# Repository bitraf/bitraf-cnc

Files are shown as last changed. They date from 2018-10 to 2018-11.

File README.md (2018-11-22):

# Bitraf-cnc
CNC-related research and projects at Bitraf

 config/	configuration for our machines

 docs/		documentation

 docs/shopbot	document Shopbot specifics
 
 [Hrbl-shopbot edition a new arduino and GRBL powered controller card for the bitraf shopbot](Hrbl-shield_readme.md)
 
 [Please contribute by discussing the open Issues!](https://github.com/bitraf/bitraf-cnc/issues)

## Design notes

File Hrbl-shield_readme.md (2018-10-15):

# Hrbl - Grbl connection shield for Arduino Nano, Shopbot version

## Status

* Under development, this is a fork of the [Hrbl shield for integrated motors](https://github.com/fellesverkstedet/fabricatable-machines/blob/master/hrbl-shield/README.md) from the [Fabricatable Machines project](https://github.com/fellesverkstedet/fabricatable-machines/wiki)
* To help, go to the [issues](https://github.com/bitraf/bitraf-cnc/issues) and find out what needs to be done or raise new issues

## Features

* A fabricatable replacement controller card for the [Shopbot PRSalpha](http://www.shopbottools.com/mProducts/prSalpha.htm)
* It has a Arduino Nano running [GRBL](https://github.com/gnea/grbl/wiki) which does the motion planning.
* It can be fed with gcode over USB using [Octoprint](https://octoprint.org/download/) or [Universal Gcode sender](https://winder.github.io/ugs_website/)
* Pluggable connections that combine all connections needed per axis in one connector per motor *(Needs work!)*
* Full optoisolation separates the computer-arduino circuit from all signal and power wires.
* Z axis milling bit probe connection with external pull-up
* Spindle on/off and speed control *(Needs work!)*
* External power loss detection, keeps the controller in ABORT mode when there is no power to the motors.
* The 2 sided card can be CNC milled with a Ø0.4 mm milling bit 
* Laser cuttable solder mask and silkscreen

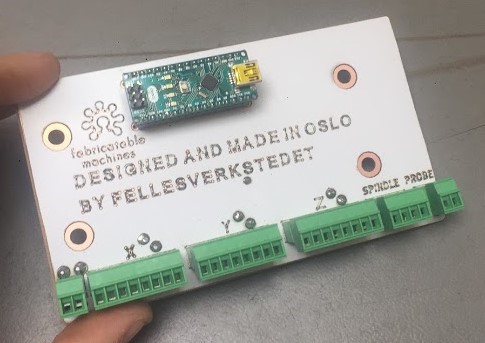
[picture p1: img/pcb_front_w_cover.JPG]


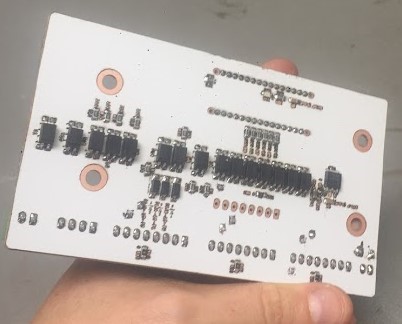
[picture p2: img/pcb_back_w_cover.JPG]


*The HRLB card that was made for [Hedy](https://github.com/fellesverkstedet/fabricatable-machines/blob/master/hedy-pcb-cnc/readme.md#hedy-pcb-mill)*

### Connections

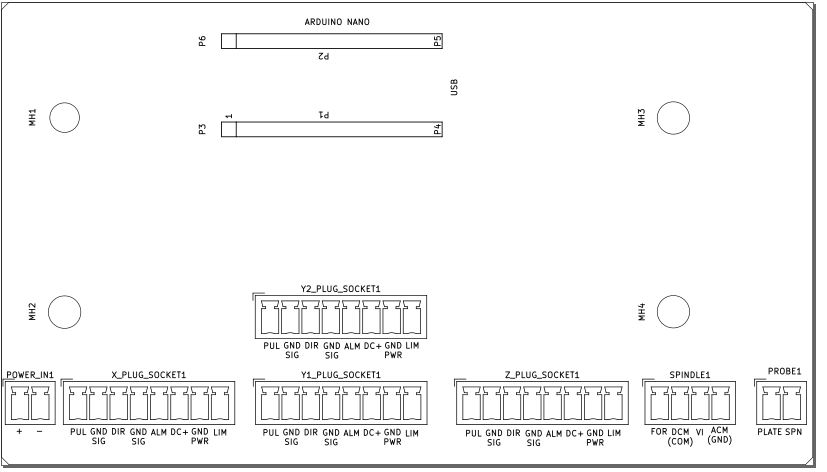
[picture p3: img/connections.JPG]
Connections


[Connections SVG](img/hrbl_shield.svg)

*These need to be reconfigured to match the connections on the shobot*

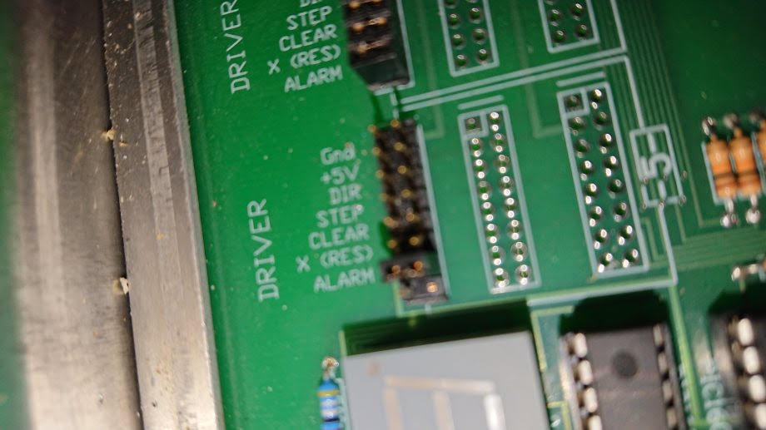
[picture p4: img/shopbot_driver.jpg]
shopbot driver pins


*Shopbot driver pins*

* Question: How does the shopbot controller connect to the limit switches?

## Files

* [All dxf files for milling and laser engraving the foil](Hrbl_for_shopbot/nano-all_DXFs.zip)
* [BOM PDF](Hrbl_for_shopbot/nano_BOM.pdf)
* [BOM ODS format](Hrbl_for_shopbot/nano_BOM.ods)

### Status

HRBL for integrated motor drivers is currently in use in:
* [Hedy v1](https://github.com/fellesverkstedet/fabricatable-machines/blob/master/hedy-pcb-cnc/readme.md) A CNC milling machine made to mill circuit boards like this one.
* [Humphrey v3](https://github.com/fellesverkstedet/fabricatable-machines/blob/master/humphrey-large-format-cnc/humphrey_v3/Readme.md) A large size CNC milling machine built as a kit by Makerspace in Brumundal.

### Firmware for the Arduino NANO

* Download this repo and go into the [Hrbl_for_shopbot/grbl_spindle_enable_no_alarm_on_boot](Hrbl_for_shopbot/grbl_spindle_enable_no_alarm_on_boot/) folder on your computer
* Open the grblUpload.ino file in the grblUpload subfolder.
* Connect the Arduino Nano, select the correct COM port and upload.
* *The config is set for spindle enable, pwm and disabled (homeing warning) alarm on boot.*
* Dowload [UGS](https://winder.github.io/ugs_website/download/) or another gcode sender
* Connect and cofigure the homeing direction, max speed, acceleration and steps per mm. Make a backup of these settings in a txt file and upload them here.
* Problems? See the [Official GRBL instructions](https://github.com/gnea/grbl/wiki)

### Dependables

* Arduino UNO
* Stepper motors with DIR and STEP pulse control interface
* 8 pole cable with 0.5mm2 wires
* Power supply and cables
* Control computer or raspberry pi
* Limit switches 
* VFD (spindle driver) communication translator *(Needs work!)*

# Notes while fabricating new version

* Careful with which layer you mirror when you mill it!
* 8mm/s @18000rpm with a Ø0.4mm 2 flute china endmill worked! (did most with 4.5mm/s)
* Attach with double sided skotch tape (Jernia-brand worked well)
* Mill and drill from the side where you will solder the most thorugh hole components first
* Drilled Ø1mm holes were too tight for the contacts, mill them to at least Ø1.2mm next time.
* Don't make the alignment holes for flipping the card too tight.

### Future improvement ideas
* HRBL-shield is potentially great to combine with [Hertz - axis monitoring board](https://github.com/fellesverkstedet/fabricatable-machines/tree/master/hertz-axis-monitor). Optimized for ihss57 integrated closed loop stepper motors.
* Create a version with a onboard 328p microprocessor to be able to skip the arduino uno altogether, remember to breakout programming pins for the MCU
* Consider replacing the 16 single channel SFH6206-3T optocouplers with 4 channel 4TLP291-4(GB) for reduced part count and cheaper BOM. 
* (From [issue 20](https://github.com/fellesverkstedet/fabricatable-machines/issues/20) consider if we should change the 5V voltage regulator.
* Establish a maximum current that we can draw through the card to the motors without overheating the traces (or ribbon cable).

# Pictures

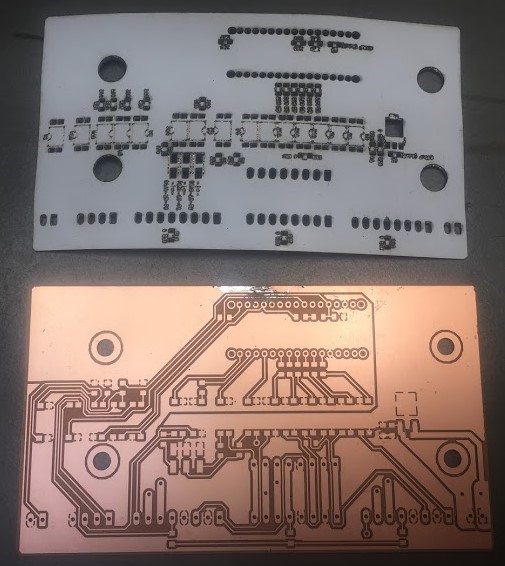
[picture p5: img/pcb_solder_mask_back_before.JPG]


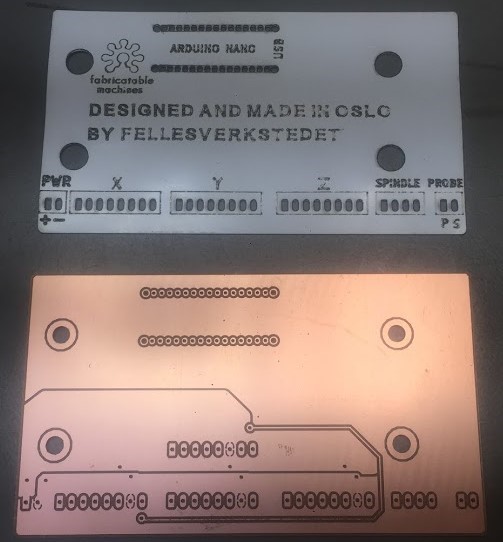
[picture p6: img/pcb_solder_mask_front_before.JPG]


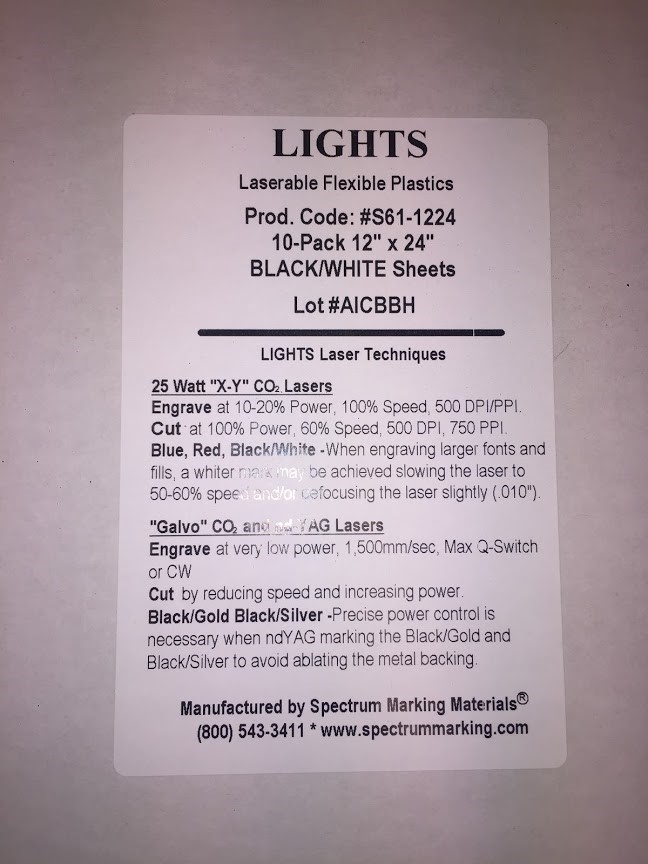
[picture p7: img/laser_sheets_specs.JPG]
Laser sheet


*Laser foil for solder mask and silkscreen*

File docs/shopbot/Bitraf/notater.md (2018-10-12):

Notater fra befaring av Bitraf sin shopbot 2018-10-11, utført av Jens Dyvik og Torfinn Ingolfsen.

 Shopbot-PC 	- datamaskin (med Windows) som benyttes til styring av shopbot

 kontroller-kort	- elektronisk "hjerne" koblet til Shopbot-PC via usb, til driverkort via multikontakt og to flatkabler

 driver-kort	- kort koblet til motordrivere, kontroller-kort, styrings-kretser og sikkerhetskrets

 VFD styring	- hastighet (usb til RS-485 eller -442) fra Shopbot-PC
		- start / stopp via kontroll signal (høyt / lavt) driver-fra kort

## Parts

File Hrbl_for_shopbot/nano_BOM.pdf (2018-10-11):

Sheet2

Type | Quantity | Designation | Package/footprint
Capacitor | | 3100nF (0.1uF) | 1206
Capacitor | | 310uF | 1206
Female header | | 1 Socket_Strip_Arduino_1x15 | 0.1”
Female header | | 1 Socket_Strip_Arduino_1x15 | 0.1”
LED | | 1LED | 1206
Linear fixed voltage regulator 5V | 1IFX27001TFV50ATMA1CT-ND TO-252-3_TabPin2
Optocoupler | | 15 SFH6206-3T | SMDIP-4
Pluggable connector female | | 2 Conn_01x02 | MCV 1,5 4-G-3.5
Pluggable connector female | | 1 Conn_01x04 | MCV 1,5 4-G-3.5
Pluggable connector female | | 4 Conn_01x08 | MCV 1,5 4-G-3.5
Resistor | | 16220 ohm | 1206
Resistor | | 60 ohm (jumper) | 1206
Resistor | | 41000 ohm | 1206
Signal diode | | 3 DIODE | SMA D or 1206

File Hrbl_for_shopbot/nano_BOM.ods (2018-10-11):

Type | Quantity | Designation | Package/footprint | Designator | Package
Capacitor | 3 | 100nF (0.1uF) | 1206 | C3,C2 | C_1206_3216Metric_Pad1.42x1.75mm_HandSolder
Capacitor | 3 | 10uF | 1206 | C6,C5,C1 | C_1206_3216Metric_Pad1.42x1.75mm_HandSolder
Female header | 1 | Socket_Strip_Arduino_1x15 | 0.1” | P1 | Socket_Strip_Arduino_1x15
Female header | 1 | Socket_Strip_Arduino_1x15 | 0.1” | P2 | Socket_Strip_Arduino_1x15
LED | 1 | LED | 1206 | D1 | LED_1206_3216Metric_Pad1.42x1.75mm_HandSolder
Linear fixed voltage regulator 5V | 1 | IFX27001TFV50ATMA1CT-ND | TO-252-3_TabPin2 | U15 | TO-252-3_TabPin2
Optocoupler | 15 | SFH6206-3T | SMDIP-4 | U16,U14,U13,U12,U11,U10,U9,U8,U7,U6,U5,U4,U3,U2,U1 | SMDIP-4_W9.53mm_Clearance8mm
Pluggable connector female | 2 | Conn_01x02 | MCV 1,5 4-G-3.5 | PROBE1,POWER_IN1 | PhoenixContact_MCV_1,5_2-G-3.5_1x02_P3.50mm_Vertical
Pluggable connector female | 1 | Conn_01x04 | MCV 1,5 4-G-3.5 | SPINDLE1 | PhoenixContact_MCV_1,5_4-G-3.5_1x04_P3.50mm_Vertical
Pluggable connector female | 4 | Conn_01x08 | MCV 1,5 4-G-3.5 | Z_PLUG_SOCKET1,Y2_PLUG_SOCKET1,Y1_PLUG_SOCKET1,X_PLUG_SOCKET1 | PhoenixContact_MCV_1,5_8-G-3.5_1x08_P3.50mm_Vertical
Resistor | 16 | 220 ohm | 1206 | R21,R12,R15,R14,R13,R11,R10,R9,R8,R7,R6,R5,R4,R3,R2,R1 | R_1206_3216Metric_Pad1.42x1.75mm_HandSolder
Resistor | 6 | 0 ohm (jumper) | 1206 | R22,R20,R19,R18,R17,R16 | R_1206_3216Metric_Pad1.42x1.75mm_HandSolder
Resistor | 4 | 1000 ohm | 1206 | R26,R25,R24,R23 | R_1206_3216Metric_Pad1.42x1.75mm_HandSolder
Signal diode | 3 | DIODE | SMA D or 1206 | S1JA-13-F3,S1JA-13-F2,S1JA-13-F1 | D_SMA_Handsoldering

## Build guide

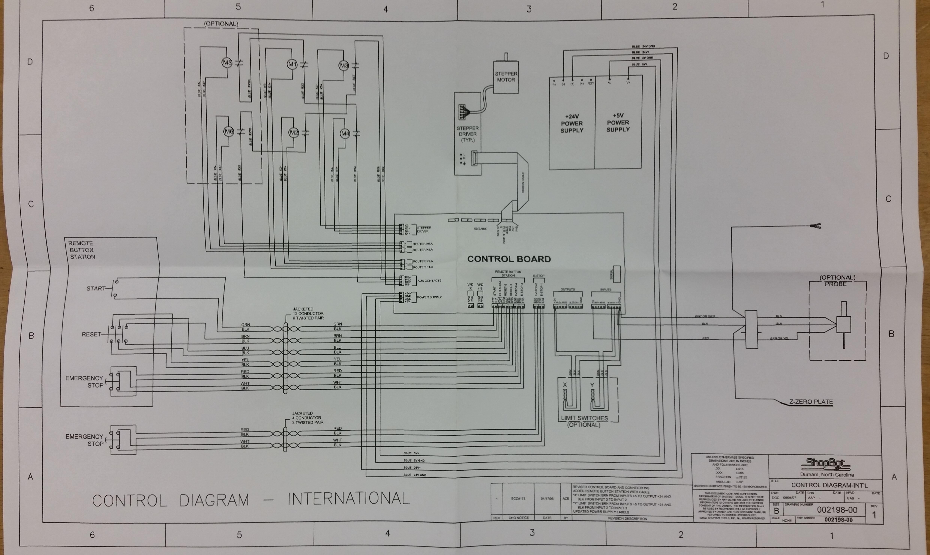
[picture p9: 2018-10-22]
docs/shopbot/Bitraf/wiring_diagrams/ShopBot_Control_Diagram.jpg

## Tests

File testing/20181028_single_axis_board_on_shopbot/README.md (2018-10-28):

# Testing of single axis borad with ShopBot driver
*28th of October 2018, by Jens Dyvik*

Video from test [here](https://youtu.be/CiLMGvgEv7U)

#### Results
- The single axis board had incorrect pinout. It seems like most pins are double on the shopbot ribbon cable. By trimming way the wrongly placed ground pins, the board became functional. Correct pinout embedded bellow
- The correct steps per mm with 5x microstepping seem to be 78. This make no sense to me. ShopBot manual on calibrating steps per mm uploaded [here](https://github.com/bitraf/bitraf-cnc/blob/master/docs/SBG%2000171%20Settings%20Unit%20Values%202014%2012%2017.pdf)
- The good news is that 5x microstepping with a 78 steps per mm setting is safely within GRBL max step rate
- The pcb traces were milled on the bitraf shopbot with 0.4mm pcb engaving bit from [this shop](https://www.aliexpress.com/item/Free-Shipping-5pcs-0-6mm-Micro-Grain-Tungsten-Carbide-End-Mill-2-flutes-HRC55-CNC-Milling/2037305989.html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), and 1mm single flute bit from VHF for holes and cutout. 

#### Next steps *(could be done with a single new board)*:
- Test the alarm output from driver. It seems to have inverted logic from the expected GRBL alarm input, a transistor or other kind of logic inverter should do the trick
- Test controlling all four motors
- Test VFD control with PWM and start/stop from GRBL
- Test aux input from safety contactor *(these might also need logic inverting)*

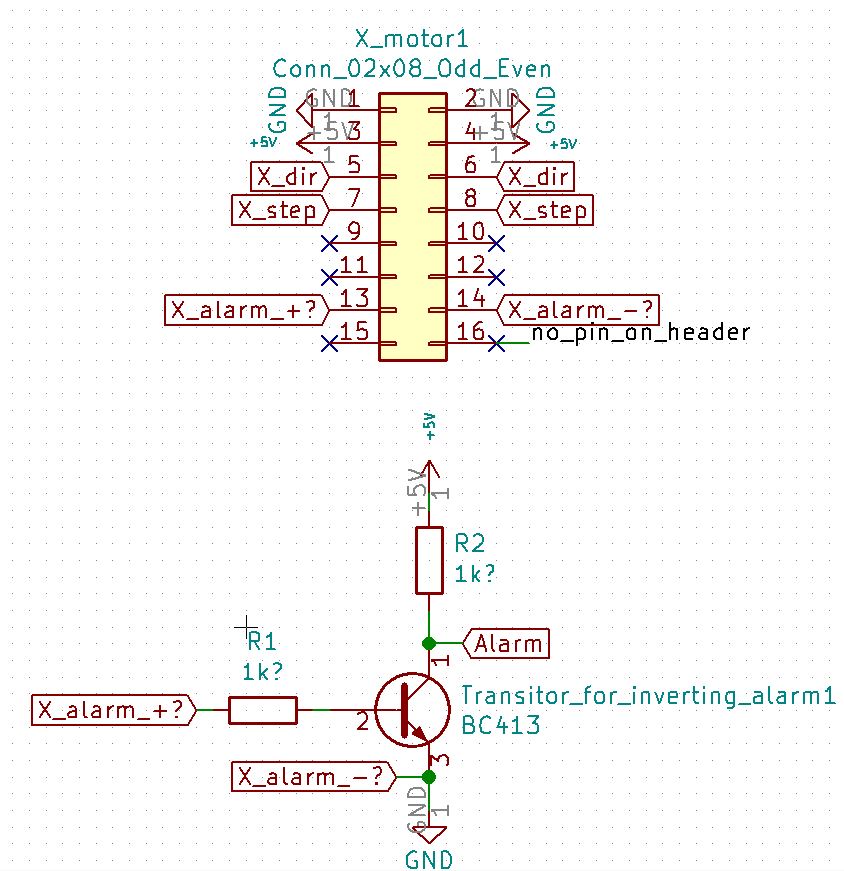
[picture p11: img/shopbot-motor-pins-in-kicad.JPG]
pins


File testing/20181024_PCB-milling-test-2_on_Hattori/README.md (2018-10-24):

Wednesday 24th, October 2018, @cisc and I did another test of milling PCB on Hattori.

Again [this](../../Hrbl_for_shopbot/single-axis-test-CNC-ready.dxf) PCB was used for testing.
We re-used the VCarve job from last time, and adapted it to new parameters and tools.

Parts:
* re-used the PCB blank from last time
* double-sided tape (different type from last time)
* isolation engraving tool (90 degrees V-bit, 0.05 - 1 mm - this is the one sold in Bitmart)
* 1mm drill bit found in the box near Hattori / Modela
* 2mm end mill also found in the box near Hattori / Modela

Process:
* first we had to remove (used a Dremel) some protruding marks on the chamfer rail bed, caused by screwing through the spoil board and into the aluminium bed.
* we mounted a new spoil board on the Hattori bed, and planed it
* mounted the PCB blank with double sided tape, taking care to ensure that it was completely flat against the spoil board
* first job: engrave tracks with isolation engraving tool; feed rate 8mm/sec, depth 0.2 mm, outline
* second job: drill holes with 1mm drill bit; plunge rate 8mm/sec
* third job; we were not totally happy with the engraved tracks, so we tried a second time, this time with 0.25 depth (other parameters the same as the first time)
* fourth job: cutout with 2mm end mill feed rate 11mm/sec, depth 2mm, pass depth 0.2mm (error on our part, we could probably have done it in one pass)

Lessons learned:
- planing the spoil board is important
- ensuring completely flat mounting of PCB blank is important
- using the right tool(s) for each job is important
- remove the bit from Hattori before cleaning the machine (avoids accidentally breaking the bit)
- tape clogs the end mill during cutout

Discovery:
- there is something wrong with the X-axis on Hattori, resulting in inaccurate positioning and poor diagonal operation. This can be seen on some of the pictures; the some of holes drilled on the PCB are shifted sideways (in other words X-axis). This also manifests as uneven clearing of material depending on which side (of copper tracks), and uneven diagonal lines / tracks.

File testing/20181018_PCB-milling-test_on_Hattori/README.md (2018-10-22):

On Bitraf build night, we (@margrav and I) did a small test trying to mill a PCB on Hattori.

[This](../../Hrbl_for_shopbot/single-axis-test-CNC-ready.dxf) PCB was used for testing.
We used VCarve; imported the DXF, and made toolpaths there. The existing spoil board on the Hattori bed was well worn, we used that.

Parts:
* PCB "blank" bought in Bitmart
* double sided tape (for attaching PCB to spoil board)
* random drill bits / end mill and V bits found in the box near Hattori / Modela (one 0.4 mm straight bit (turns out this is a drill bit) and one 0.2mm V-shaped 30 degrees bit. Pictures in the images directory)

Lessons learned:
- using an well worn spoil board is unwise; you should start with a freshly planed spoil board
- double sided tape might not be the best way to fix a PCB blank to the spoil board
- drilling holes with an 1 mm tool (we're not sure if it is a drill bit or an end mill) worked reasonably well
- milling tracks with an 1 mm (or 0.5 mm) tool is difficult, the tools breaks easily
- milling tracks with a V-bit is better;
- - the tool survives
- - the result has rough edges
- it is difficult to find the correct depth to mill at
- if the PCB blank is not completely flat; the result will be uneven (and the resulting PCB unusable)

Images and videos in the respective sub-directories. Edit: videos are too large for Github. Must be stored somewhere else
(or edited down to acceptable size).

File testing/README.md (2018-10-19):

Here we can have subdirectories for tests / testing that we do on or with the CNC machines.
Preferably, each test should be documented in it's ownb subdirectory, with directories for images, video and so on
as required.

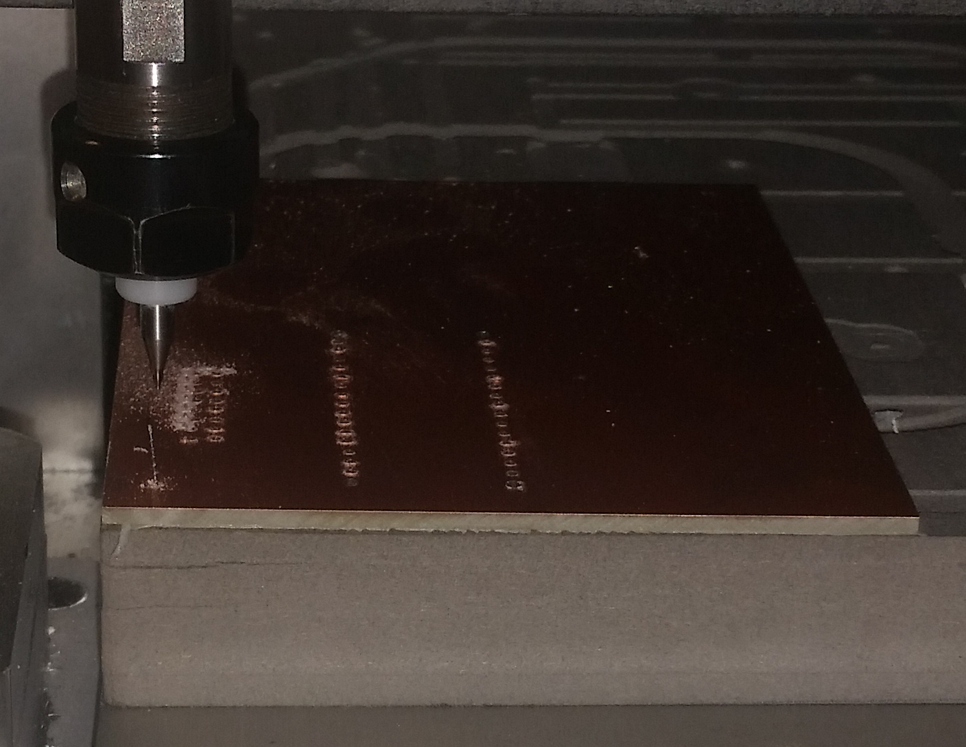
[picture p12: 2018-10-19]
testing/20181018_PCB-milling-test_on_Hattori/images/milling_2_20181018_221713.jpg

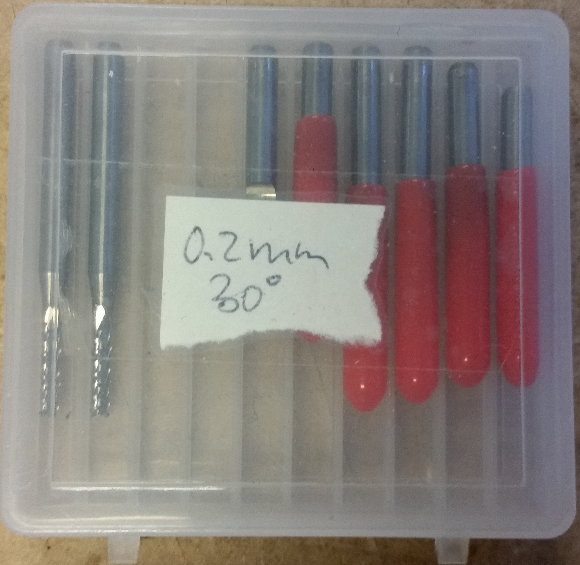
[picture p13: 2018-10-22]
testing/20181018_PCB-milling-test_on_Hattori/images/bit_v-shaped_30_degrees_0.2mm_1.jpg

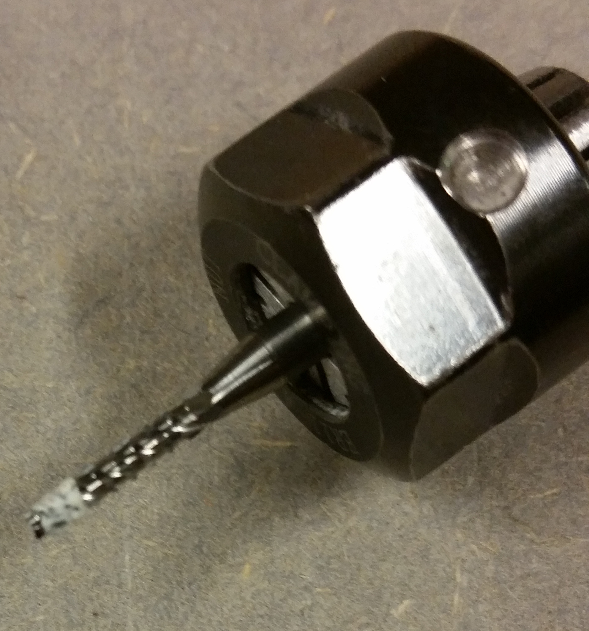
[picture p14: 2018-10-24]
testing/20181024_PCB-milling-test-2_on_Hattori/images/cutout_mill_with_tape_residue.jpg

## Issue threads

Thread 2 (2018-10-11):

Limit switches

Jaknil, 2018-10-11:
* How does shopbot connect to it's limit switches? Bonus: Are there any connection points near the stepper drivers?
* Are they normally closed or normally open?
* Do we need to feed them power via the card or is that taken care of already?

JensDyvik, 2018-10-11:
I have planned to feed the sensors 24V through our HRBL card. This kind of power distribution is already implemented in the fabricatable machines version HRBL shield.

The pin spacing on the shopbot connector is 5mm with 6 pins in a row. The last pin is not in use. So if we add a connector with 6 male pinsto our card it should be quite plug and play to connect the sensors. In this [image](https://raw.githubusercontent.com/bitraf/bitraf-cnc/master/docs/shopbot/Bitraf/images/Shopbot_kontakter_driver-kort.jpg) we have disconnected the relevant plug.

I can not remember if the sensors are NC or NO. But isnt that easy to change in GRBL firmware anyway?

Do note that we need to retrofit a sensor for the Z axis so that we can have autohoming. I suggest we use the fabricatble machines standard type of sensor. This one also works on 24V.

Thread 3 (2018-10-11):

Stepper drivers

Jaknil, 2018-10-11:
What does the pins on the driver do? Check these:
* GND
* +5V (Does it provide or need 5V here?)
* DIR (Most likely: 5V HIGH/LOW  sets direction)
* STEP (Most likely: short 5V HIGH pulses increments the stepper motor a step/microstep)
* CLEAR (Possibly: Clear alarm by 5V HIGH or LOW?)
* X ( RES) (?)
* ALARM (Assume: Goes 5V HIGH or LOW when the stepper can't reach position, which one?)

What is the pin spacing on the card? (To be able to design a connector)

What does the second pin do for each pin? Is it to be able to pull it HIGH/LOW permanently?

How many steps per mm does the shopbot take? Is it compatible with the standard GRBL pulse length?

Bonus: Is there any settings we want to tweak on the stepper driver like closed loop error tolerance?

Jaknil, 2018-10-16:
I ran the numbers and the setting for 1000 steps / revolution should work fine. We will get a max speed of 542mm/s (32,5m/min) at 30kHz. The smallest movement will then be 0,02mm (/ step) which isn't fantastic but should absolutely be good enough. (Calculated for 130mm pinon).

What I couldn't calculate my way to is the value of  97.748705 steps per mm. Were did that come from? Is it a shopbot setting? Odd if so.

Value | Unit | Comment
-- | -- | --
1000 | puls/rot pre gearbox | Stepper driver setting
7,2 | gearbox | ShopBot PRSalpha
7200 | steps per rot, |  
0,05 | deg per pulse ink gearbox |  
130 | cicumference ca? |  
0,018 | mm/pulse | Min movement, ok
55,38 | steps/mm with these settings |  
97,748705 | steps per mm | Shopbot vaule from jens?
30000 | puls per sec max from arduinno |  
4,17 | rotations per sec max |  
541,67 | mm/s | Max travel speed, more than needed
32,5 | m/min |  
45,7 | m/min | shopbot stock max speed, never used

JensDyvik, 2018-10-16:
I am puzzled as well by the default values in the shopbot firmware.

The shopbot drivers are capable of microptepping x5 and x10. They can also do half steps. I am not sure what stepping level shopbot3 uses. Default shopbot3 settings do use different step levels for jog and and cut commands. If our current setting is 500steps *(before gearing)* for jogs and 1000 *(before gearing)* during cuts, we are all good with the GRBL firmware.

If what we are accustomed to today is 5,000 or 10,000 steps *(before gearing)* during cuts, we need to do some testing to verify that the reduction in motion smoothness and precision is acceptable.

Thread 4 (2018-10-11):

Spindle control

Jaknil, 2018-10-11:
How to interface our new controller with the spindle on the shopbot?

The situation:
HRBL controls one optocoupler transistor to turn on the spindle in the forward direction and another to create a 1kHz PWM for speed control.

The shopbot Variable Frequency Drive (VFD) drives the spindle. The default shopbot way of controlling it is via a 2 pin MEMOBUS/Modbus comm. RS-485/422 serial communication. [ Here is the shopbot manual for connecting it](http://www.shopbottools.com/ShopBotDocs/files/RPMControllerYaskawa%202015%2004%2006.pdf)

And here is the [VFD sellers product page](https://www.yaskawa.com/products/drives/industrial-ac-drives/microdrives/v1000-drive)

Alternatives:
1.  We can use another microcontroller to interpret between the PWM signal and the serial communication.
2. We can use analog control of the VFD like we do in fabricatable machines. There is an option on the VFD to control it with a reference voltage between 0-10V and they provide a 10,5V source

Nr 2 Sounds super easy, no new components required, we just need to route the traces differently.

If you are OK with nr2 then I can implement it on the card.

tingox, 2018-10-11:
Either way, we should test that it works the way we want before committing to a solution. Solution nr 2 might work differently from the way it works today (different range, responsiveness, or other) in a way that makes us unhappy. If it works exactly like today we're fine.

JensDyvik, 2018-10-11:
I agree that we should test as soon as possible. It is easy to open the VFD case and connect new wires. It might be that the VFD needs reprogramming to listen to pwm input instead of RS-485. In that case we need to be sure that we can program it back easily too to avoid a lengthy downtime after testing.

@Jaknil can you take responsibility for testing pwm from an arduino to the VFD?
@tingox if jakobs test fails, can you write an arduino sketch for converting pwm to RS-485 and source the serial interface hardware(shield)?

Note that the shopbot v1000 VFD is a special IP66 type and might have differnt programming/interface. I have not found the v1000 ip66 manual online yet

Jaknil, 2018-10-12:
Yes I can be responsible for testing analog PMW control on the bitraf shopbot. I assume the fellesverkstedet ones are not easily accessed for testing? It does need repogramming and dip switch changes. I will read up properly before and

I have simulated some PWM smoothing circuits now using [this site](http://sim.okawa-denshi.jp/en/PWMtool.php) and think R 1000 ohm and C 10uF are good values for the PWM smoothing. It leaves a 2,5% noise in RPM but has a super fast response for future cornering RPM control. It can do 0-100% in 0.05 s.
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

JensDyvik, 2018-10-12:
Super. Yes, definitely better to test VFD control by PWM at bitraf.

2.5% noise with super fast response rate sounds great. Without any filter we only have very minor fluctuations in spindle speed on Hattori at bitraf.

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

Jaknil, 2018-10-12:
@tingox offered to build the test circuit. I think this is what we need:
I have optocouplers if there are no nice transistors kicking around in the lab.

Let's mark the wires as well!

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

I uploaded the Kicad folder to the [repo](https://github.com/bitraf/bitraf-cnc/tree/master/Hrbl_for_shopbot/pwm_smooth)

Jaknil, 2018-10-12:
Reminder to self: Need to double check the R and C values for 10V

JensDyvik, 2018-10-12:
Awesomely fast work! Looking forward to hearing the results.

I have started work on super simple test board for testing to controll only one driver. It has only one male 2x8 pin connector for the ribbon cable to the driver and female connectors for an arduino nano.

tingox, 2018-10-15:
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
Here is the test circuit (without wires) @cisc and I built it, and he verified the wiring
Parts substituted:
2N3904 transistors
10 mikroF 25V electrolytic capacitor
I have checked the datasheet, and 2N3904 should work for the voltages and currents we will use. I'm not sure if the electrolytic capacitor is a good enough substitute, @jaknil ?

tingox, 2018-10-18:
Questions we need to figure out before the test:
- security circuit: do we need to bypass it (to run with the door to the electronics open for example)?
-- and if needed, how?
- mains power to the VFD: just rig a signal that activates the contactor? Or do we need to do it another way?

Jaknil, 2018-10-19:
The spindle test was't successful but it wasn't a failure either. We couldn't set all the parameters for some reason and we accidentally used an old 0.9 version GRBL which used a different pinout from what we wired it for. We learned a bunch though and could restore it to working order inside our booking.

Here is the full test instructions and test log: https://docs.google.com/document/d/1vSm9jWW1w2j-wPlAy6cMJmsO1I4x_Cvt3CuZz1CbSg8/edit?usp=sharing

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

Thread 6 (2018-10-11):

Requirement: after emergency stop (estop) is activated, a secondary action is required to resume operation

tingox, 2018-10-11:
After emergency stop (estop) is activated, it is not enough to remove the estop signal to resume operation, in addition a secondary action is required (example: press of a reset button).

JensDyvik, 2018-10-11:
If we use the same SICK safety hardware as in the fellesverkstedet [prototype](https://github.com/fellesverkstedet/European-ShopBot-installations/wiki/Bill-of-materials) we will have a nice reset button next to the e-stop that blinks when it should be pressed.

If we keep the existing shopbot control card as a safety card we have an existing reset button.

It is important that the grbl abort pin gets a high signal when the e-stop is pressed. The easiest might be to to keep our existing 5V drop watchdog safety on the HRBL card. The shopbot controll cabinet already have a 5V powersupply.

Currently the shopbot safety bar only pauses the controll. It does not kill power to vfd and drivers via contactors. We need to decide if we should keep a similar configuration or kill power with the bar. If we implement autohome it should not be any trouble to kill power with the safety bars.

In a later stage of this development we should make a proper safety wall ala [fellesverkstedet](https://youtu.be/FSmV1vMxN_A). This has already been discussed and informally approved at bitraf

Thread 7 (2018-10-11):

Requirement: auxilliary signal from contactors shall activate abort signal

tingox, 2018-10-11:
The shopbot has contactors that disable (cut) power to stepper motor drivers and VFD when alarm or emergency stop signal happens. These contactors have an auxillary signal (24V) that is used to detect if the contactor works.

This auxillary signal shall be used to activate the abort-signal on the new controller if one of the contactors fail.

JensDyvik, 2018-10-11:
as discussed in this [issue](https://github.com/bitraf/bitraf-cnc/issues/6#issuecomment-429093533) we have in the existing hrbl card a detection of 5V loss that sets the abort high. but currently the contactors does not kill power 5V power supply. since the contactors already have a 24V guidance (aux) signal it should be super easy to listen to this instead of 5V power loss

Jaknil, 2018-10-12:
Yes that can easily be implemented. Also with a information LED like discussed in Issue #8

"but currently the contactors does not kill power 5V power supply" - Doesn't that depend on how we power our card? The on-card 5V regulator (needed for the optocouplers) can be powered by the stepper driver PSU like we did on Hedy? The 5V from USB is separate.

JensDyvik, 2018-10-12:
The shopbot does not have a PSU for the drivers. The drivers run directly on 220V single phase power.

The shopbot cabinet has a 24v and a 5v power supply. The safety contactor does not kill their power.

It might be unecceary complex to set up an extra relay/mosfet to kill power input to our card, when all we need is to listen to the 24V aux signal from the safety contactors.

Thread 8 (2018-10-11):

errors: better feedback

tingox, 2018-10-11:
We want better feedback about errors: is the cause of an error an alarm from a stepper motor driver, from emergency stop (estop), or something else?

tingox, 2018-10-11:
The final version should report errors via the user interface / control program. for a first version a display or some LEDs would be acceptable.

JensDyvik, 2018-10-11:
It would also be great to report which axis has created the alarm. For instance an alarm message like "X axis is not able to move. Check for obstructions and restart" would be very amateur friendly

Jaknil, 2018-10-12:
In this first version we can implement LEDs on the front of the card with laser-silkscreen information about what caused the error.

Sources of error which can be shown with LEDs:
* One for each axis motor(s) driver in ALARM state
* External power loss
* Safety contactor not connected

The arduino already has leds that indicate successfull USB connection (the power led) serial comminication (the RX TX LEDS) and spindle RUN signal (pin 13 built in led).

The Universal Gcode sender interface can already detect and show if we are in a general alarm state, which limit switch or if the probe is triggered. So I don't think we need leds for these.

JensDyvik, 2018-10-12:
I vote that we dont implement any of this in the first version of the card. Our task list is already quite long. Aslo, the oriental motors drivers already have nice blinking leds to indicate state

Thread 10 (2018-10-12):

Z probe: some tools (some milling bits) are not electrically conductive

tingox, 2018-10-12:
The current idea for a Z probe is to use a metallic plate off the work area somewhere to measure correct Z height / zero by measuring electrical conductivity between the plate and the tool.
However, some tools (example: diamond milling bits) are not electrically conductive. Shopbot sells a pressure sensitive Z-Zero plate https://store.shopbottools.com/products/pressure-sensitive-z-zero-plate
that can be used in this situation.
Should we select electricallly conductive or pressure sensitive technology?
Or can we have both?

JensDyvik, 2018-10-12:
I vote that buy and implement the shopbot pressure probe. It would be nice to experience pros and cons with this one compared to a conductive aluminium plate.

We already have good experience with self made alu probe plates, and can easily revert to this if are not happy with the pressure sensitive probe

Jaknil, 2018-10-15:
Found the manual for it: http://www.shopbottools.com/ShopBotDocs/files/PressureSensitiveZzero.pdf

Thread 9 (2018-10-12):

Dynamic spindle RPM when cornering (future feature discussion)

Jaknil, 2018-10-12:
I suggest we break out the discussion of dynamic spindle control to this issue. @JensDyvik

Summary of the idea: We want to use the[ laser mode in GRBL](https://github.com/gnea/grbl/wiki/Grbl-v1.1-Laser-Mode) to dynamically slow down the spindle as the feed speed is decelerated due to cornering and the like. If done right this will give us a more constant chip load and reduce unnecessary heat buildup massively when using high rpm spindles.

Things we will need to look into:
* GRBL default laser mode turns spindle off when jogging. Some workaround seems to exist. If we use bark beetle I assume we could also program jogs as air-cuts.
* Spindle acceleration is slower than laser power change "acceleration"
 Example:
60000 Rm spindle, 0.1mm chipload single flute = 100mm/s feed.
If we want to do a 90 deg corner and maintain chipload we should in theory go from 100mm/s and 60000 rpm to 0mm/s and 0 rpm (and then opposite when accelerating), this will take 0,3s if we have a 300mm/s^2 feed acceleration. I doubt the VFD can get the spindle from full rpm to zero, or worse zero to full in 0,3 s.
So then we can either let the VFD try it's best and adjust the RPM less than all the way during short duration speed changes or we lower the acceleration on the feed axes so that the VFD+spindle acceleration can keep up.
Practically I guess we can start with setting the spindle to max acceleration and see how high feed acceleration it can keep up with before we notice problems.

I guess low melt-point plastics will be an acid-test to see if we have got it right.

Looking forward to trying it!

JensDyvik, 2018-10-12:
I dont think we need to worry to much about spindle speed up delay.

1. With constant spindle speed we already have quite good performance
2. The biggest problem is not corners but cutting jobs with a lower speed over a longer time. For instance small diameter helical entry into metal when using adaptive clearing. Or many small features in a row for instance when milling small teeth. So that makes spindle responsiveness even less of an isssue.

I think the GRBL firmware allows PWM duty cycle to be mapped to a minimum value. If this is correct i suggest we start testing at with a range from 25% to 100%. I dont think we have any need for zero spindle spindle in corners.

I think starting with testing with Bark Beetle is a good idea. If these tests are successful we can dive into modding the GRBL firmware so that dynamic laser mode works with M3 instead of M4 commands and that the spindle will spin during G0 moves. This will allow generic post processors to work with dynamic spindle speed.

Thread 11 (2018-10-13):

Octoprint GRBL plugin is unstable

JensDyvik, 2018-10-13:
I have successfully tested the Octopi image on a raspberry pi controlling GRBL on an Arduino Nano. I followed the instructions on the [fabricatable machines repository](https://github.com/fellesverkstedet/fabricatable-machines/wiki/Electronics) to install and set up.

I am able to load and run jobs. But octoprint with the [grbl support](https://plugins.octoprint.org/plugins/octoprint-grbl-plugin/) plugin behaves unstable and freezes often. After a freeze the octoprint servers needs to be restarted. We need to find a way to improve the plugin. It could be great if our fixed could be sent as a pull request to the [plugin repo](https://github.com/mic159/octoprint-grbl-plugin)

### Issues to fix
- GRBL alarm commands are not well handled and "freezes" octoprint so that a restart is required. It would be super if Octoprint could automatically disconnect and reconnect or send a "clear alarm" command after an alarm.
- It could also be great to map the error codes to the [official descriptions](https://github.com/gnea/grbl/wiki/Grbl-v1.1-Interface#grbl-response-messages) to help users troubleshoot.
- Octoprints sends unnecessary marlin commands that seem to sometime make GRBL go to an alarm state. Typically (M1xx).
- After a few minutes of being idle Octoprint seems go into a time out error because it expected a response from GRBL
- Pressing the "Stop" button in the octoprint interface stops the machine movements but not the spindle.

### Tweaks I have made to make Ocoprint work on GRBL
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
Turn off "Send a checksum with a command" *(This is also mentioned in the [GRBL plugin repo](https://github.com/mic159/octoprint-grbl-plugin))*

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
Set the error Handling to "Cancel any ongoing prints". I think ignoring them entirely might be risky.

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
Set the temperature query interval to daily. If this one is to frequent it impacts the streaming of coordinates and creates an error response. This solution is mentioned in [this issue](https://github.com/mic159/octoprint-grbl-plugin/issues/3) in the plugin repo.

JensDyvik, 2018-10-14:
### Update:
It seems like the the communication timeout can be disabled with the following settings. Testing so far is promising. *(Not sure if there is ant risk involved in disabling the communication timeout)*:

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

synman, 2019-03-13:
I'm working through this myself with an Eleksmaker A3.  I am periodically getting grbl error 9, 11, and 24.

I'll check my intervals tonight (they are currently set to 2 seconds) and see what I have for consecutive timeouts ( I think I already have them at zero)..

I did create a plug-in of my own for handling soft reset 0x18 and eating the hardcoded M115 Gina sends in comms.py.  I'm not sure why she didn't bundle it within the printer safety plug-in itself.

JensDyvik, 2019-03-13:
Great to hear that there are more minds working on this. Thank you for sharing and please keep us posted on your progress!

synman, 2019-03-13:
killing the temperature polling solved my problems.   I do find it a little annoying that I can't (inherently) get position updates / etc while executing, but all other benefits (I have been using Octoprint on my 3d printer for years) far outweigh that and I can probably figure some way around it.

I've disabled the temperature and gcode tabs completely and am considering doing the same for the Control tab.   I'm currently undecided on whether I should work with the exiting control tab or create my own.

A couple other items I'm looking into:

- GCode Viewer (while it is typically just one layer I should be able to plot progress
- Framing (this is a must have for me... I need something to evaluate loaded gcode, determination min / max x and y, turn the laser on weak mode and draw the boundaries)

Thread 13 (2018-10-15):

Help needed for milling single axis test board

JensDyvik, 2018-10-15:
We have the production DXF ready for a single axis board [here](https://github.com/bitraf/bitraf-cnc/blob/master/Hrbl_for_shopbot/single-axis-test-CNC-ready.dxf). Kicad source is also in the repo.

Does @tingox or @Jaknil have the opportunity to mill this at bitraf?

The board is single sided and designed for 0.4mm or smaller milling bits. PCB stock can be found in bitmart.

The goal with this board is to:
- verify that we can control the oriental motors drivers with grbl,
- check if we have understood the pin connections correctly
- check if the 30000HZ limit of grbl will give us sufficient top speed

tingox, 2018-10-16:
there are free slots (in the booking calendar) this week, but I have no experience milling PCB's, so I would need help from someone with experience.

CISC, 2018-10-19:
Using random bits lying around was probably not a recipe for success (nor was using a rather well used spoil board). :)

We have a specific tool for this in Bitmart BTW, the Isolation Engraving bit which combines a tiny V-bit with a short straight flute.

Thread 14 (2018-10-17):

Features list for control interface

Jaknil, 2018-10-17:
I think it would be good to collect and group the features we want or need to see for controlling the shopbot at bitraf. This is a thread to collect and discuss importance of different features. Try describing what a feature does instead of what it doesn't do, it makes it easier to come up with solutions.

How to implement should be discussed in separate threads.

**Bare bones necessary features:**
* Unsafe use is hindered (safety bar, chuck tool detector)
* Emergency stop
* Simple (re)boot procedure (ex blinking reset, informative pop ups or checklists)
* Spindle warmup routine
* Access gcode file
* Load gcode file
* Homeing
* Probeing
* Run Job
* Move away from work area (several positions or free jogging)
* Interface/special settings can be reset to defaults

**Highly appreciated features:**
* Pause / Resume
* Preview of the toolpath
* Home and probing is done automatically
* Go to toolchange position
* Easy to understand interface (only relevant information present)
* Persistent interface (no conflicting windows)
* Robust, free from disconnects, errors and crashes.

**Appreciated features:**
* Toolpath is screened for errors
* Material thickness verification
* Bit size verification
* Uses a straight GRBL post
* Advanced features available to power users
* Error interpretation and pop up suggestions

Nice to have feaures:
* Toolpath is projected onto work area
* User is guides through steps (load file, toolchange, error handling)

Please add features and post arguments for which should move categories.

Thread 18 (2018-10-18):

Shopbot: document the wiring diagrams

tingox, 2018-10-18:
Inside the door to the electronics box is an envelope with wiring diagrams (power and control) for the Shopbot. We should make an electronic copy (mobile photo - convert to PDF?) of them and upload here.

tingox, 2018-10-22:
pictures (jpg) of the wiring diagrams added here: https://github.com/bitraf/bitraf-cnc/tree/master/docs/shopbot/Bitraf/wiring_diagrams

Closed 2018-10-22.

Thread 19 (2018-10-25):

Hattori: there is a problem with the X-axis, giving inaccurate positioning

tingox, 2018-10-25:
there is something wrong with the X-axis on Hattori, resulting in inaccurate positioning and poor diagonal operation. (Apparently, some people have known about this problem for some time too. We should improve our issue documenting procedure).

We should open up Hattori and check the X-axis to figure out what the problem is:
- something wrong with the cog wheel?
- something wrong with the toothed rack?
- dust / debris build up?
- or something else?

Getting access to the back side of Hattori is not easy with the current way it is mounted into the cabinet. Fixing / improving access is a separate issue.

tingox, 2018-11-03:
New information received from the creator of Hattori a few days ago: the "tightness" of the X-axis has been there from day one. His suggestion is to build a newer, better machine. He thinks the problem is either from the implementation or the design of the machine.

Reminder to self: ask about the other Hattori: does it have the same problems as this one?

tingox, 2018-11-05:
On Kuben they have modified the glide blocks (POM) on the X axis by removing some material with a Dremel, effectively creating "pockets" and less surface (= less friction) between glide blocks and the other part. (This workaround increases dust accumulation in the modified area)

tingox, 2018-11-05:
Another (better) option is to replace the current X-axis on Hattori with the new type of axis (using ball bearings), as used in machines like [Hedy](https://github.com/fellesverkstedet/fabricatable-machines/tree/master/hedy-pcb-cnc).

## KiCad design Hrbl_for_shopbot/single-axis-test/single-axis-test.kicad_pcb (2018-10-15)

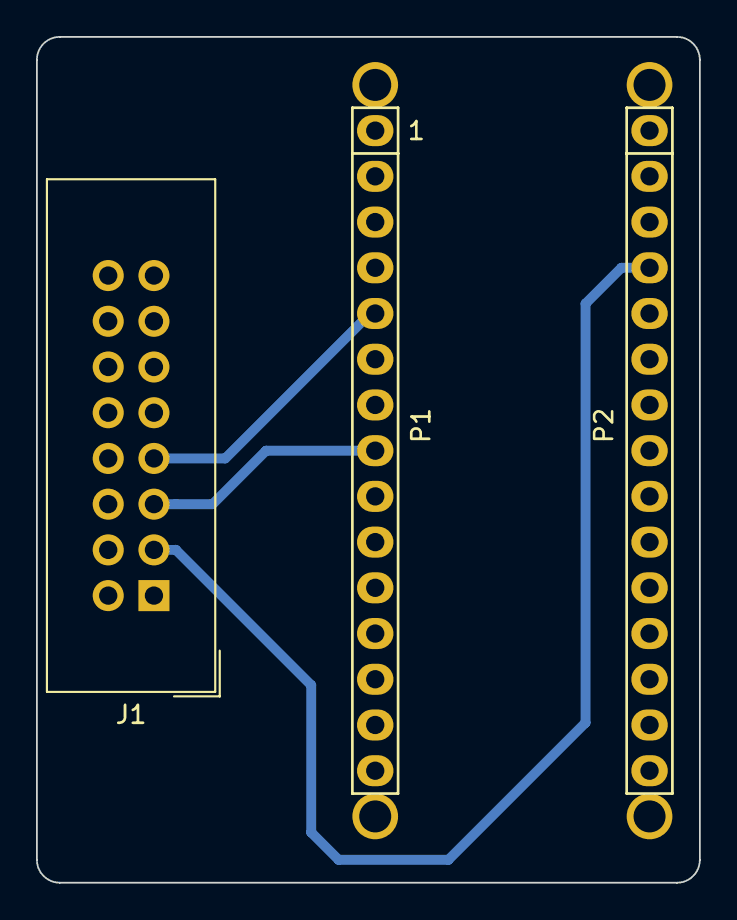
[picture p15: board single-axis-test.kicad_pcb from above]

Board: 2 copper layers, 36.8 x 47.0 mm, 7 parts (0 on the bottom side), 4 nets.

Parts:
J1: Conn_02x08_Odd_Even; IDC-Header_2x08_Pitch2.54mm_Straight
P1: Digital; Socket_Strip_Arduino_1x15
P2: Analog; Socket_Strip_Arduino_1x15
P3, P4, P5, P6: CONN_01X01; 1pin_Nano

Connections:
+5V: J1.3, P2.4
/DIR: J1.5, P1.8
/STEP: J1.7, P1.5
GND: J1.1, J1.2, J1.4, J1.6, J1.8, J1.10, J1.12, J1.14, P1.4, P2.2

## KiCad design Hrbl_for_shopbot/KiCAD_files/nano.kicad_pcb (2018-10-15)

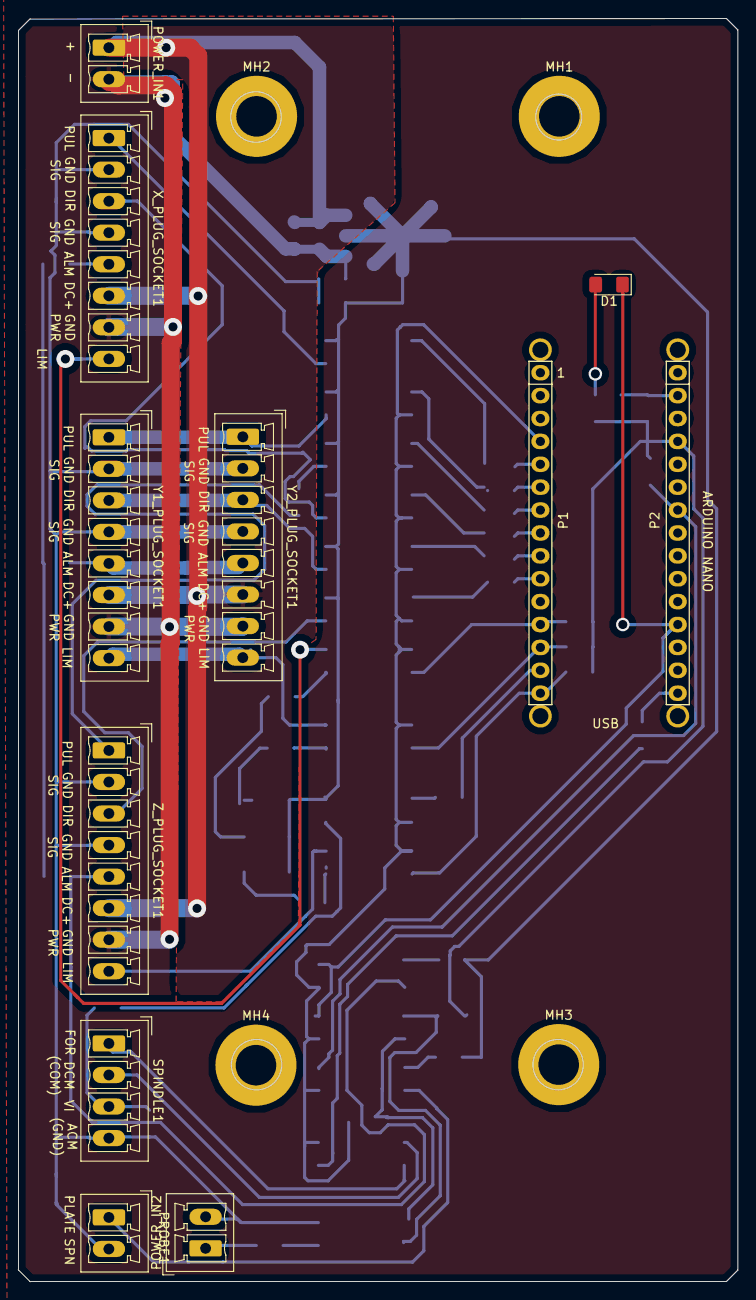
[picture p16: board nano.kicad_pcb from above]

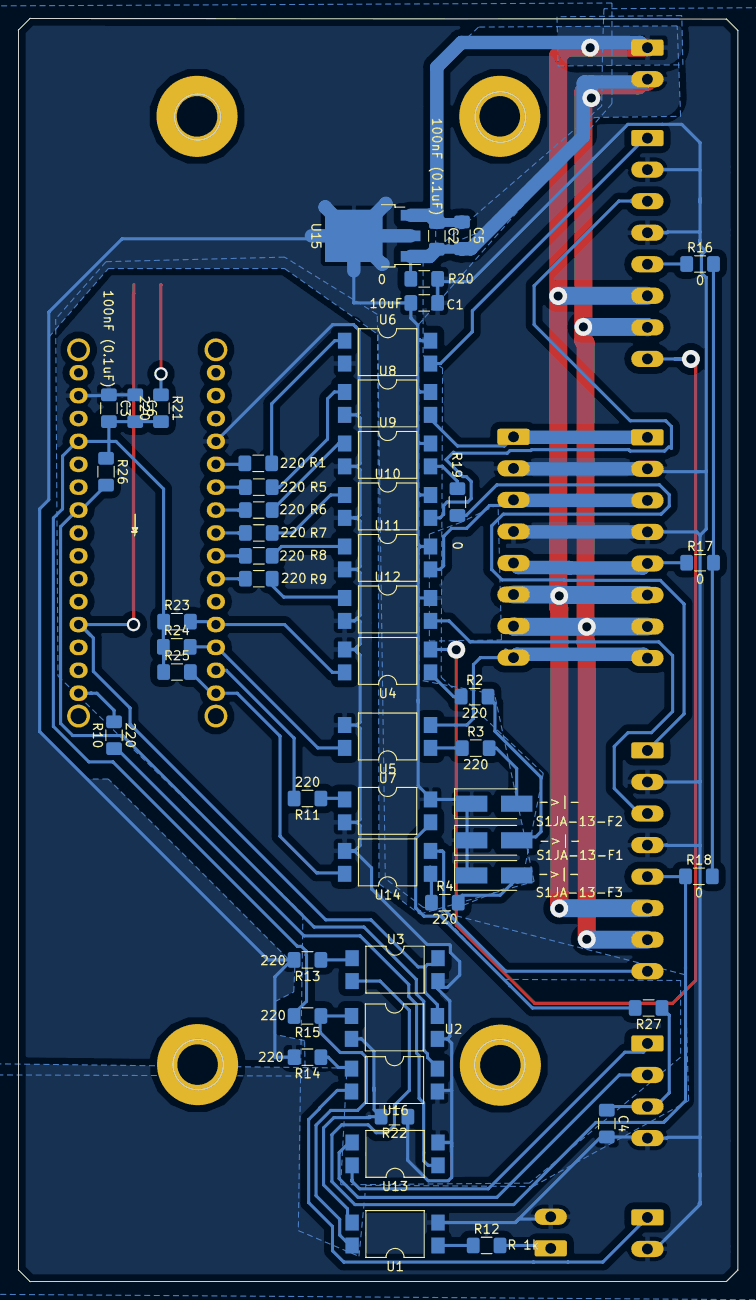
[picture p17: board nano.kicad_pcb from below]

Board: 2 copper layers, 79.8 x 140.1 mm, 71 parts (52 on the bottom side), 56 nets.

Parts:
C1, C4, C5, C6: 10uF; C_1206_3216Metric_Pad1.42x1.75mm_HandSolder
C2, C3: 100nF (0.1uF); C_1206_3216Metric_Pad1.42x1.75mm_HandSolder
D1: LED; LED_1206_3216Metric_Pad1.42x1.75mm_HandSolder
MH1, MH2, MH3, MH4: MountingHole; MountingHole_4.5mm_Pad
P1: Digital; Socket_Strip_Arduino_1x15
P2: Analog; Socket_Strip_Arduino_1x15
P3, P4, P5, P6: CONN_01X01; 1pin_Nano
POWER_IN1, POWER_IN2: Conn_01x02; PhoenixContact_MCV_1,5_2-G-3.5_1x02_P3.50mm_Vertical
PROBE1: Conn_01x02; PhoenixContact_MCV_1,5_2-G-3.5_1x02_P3.50mm_Vertical
R1, R2, R3, R4, R5, R6, R7, R8, R9, R10, R11, R13, R14, R15, R21: 220; R_1206_3216Metric_Pad1.42x1.75mm_HandSolder
R12, R27: R 1k; R_1206_3216Metric_Pad1.42x1.75mm_HandSolder
R16, R17, R18, R19, R20, R22: 0; R_1206_3216Metric_Pad1.42x1.75mm_HandSolder
R23, R24, R25, R26: 1000; R_1206_3216Metric_Pad1.42x1.75mm_HandSolder
S1JA-13-F1, S1JA-13-F2, S1JA-13-F3: DIODE; D_SMA_Handsoldering
SPINDLE1: Conn_01x04; PhoenixContact_MCV_1,5_4-G-3.5_1x04_P3.50mm_Vertical
U1, U2, U3, U4, U5, U6, U7, U8, U9, U10, U11, U12, U13, U14, U16: SFH6206-3T; SMDIP-4_W9.53mm_Clearance8mm
U15: IFX27001TFV50ATMA1CT-ND; TO-252-3_TabPin2
X_PLUG_SOCKET1: Conn_01x08; PhoenixContact_MCV_1,5_8-G-3.5_1x08_P3.50mm_Vertical
Y1_PLUG_SOCKET1, Y2_PLUG_SOCKET1: Conn_01x08; PhoenixContact_MCV_1,5_8-G-3.5_1x08_P3.50mm_Vertical
Z_PLUG_SOCKET1: Conn_01x08; PhoenixContact_MCV_1,5_8-G-3.5_1x08_P3.50mm_Vertical

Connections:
5V_ISO: C1.1, R13.2, R14.2, S1JA-13-F1.1, S1JA-13-F2.1, S1JA-13-F3.1, U6.4, U7.4, U8.4, U9.4, U10.4, U11.4, U12.4, U15.2
24V_CONTACTOR_SIGNAL: POWER_IN2.1, R12.2
+5V: C3.2, C6.2, P2.4, R15.2, R21.2, R23.1, R24.1, R25.1, R26.1
+36V: C2.1, C5.1, POWER_IN1.1, U15.3, X_PLUG_SOCKET1.6, Y1_PLUG_SOCKET1.6, Y2_PLUG_SOCKET1.6, Z_PLUG_SOCKET1.6
/DCM(COM): SPINDLE1.2, U13.3
/FOR: SPINDLE1.1, U13.4
/PROBE_PLATE: PROBE1.1, U16.2
/Reset: P1.3, P2.3
/VI: R27.2, U7.3
ABORT: D1.1, P2.12, U2.4, U3.4
ALARM_IN: R16.1, R16.2, R17.1, R17.2, R18.1, R18.2, U3.2, X_PLUG_SOCKET1.5, Y1_PLUG_SOCKET1.5, Y2_PLUG_SOCKET1.5, Z_PLUG_SOCKET1.5
DIR_X: P1.8, R7.2
DIR_X_OUT: U10.3, X_PLUG_SOCKET1.3
DIR_Y: P1.9, R8.2
DIR_Y_OUT: U11.3, Y1_PLUG_SOCKET1.3, Y2_PLUG_SOCKET1.3
DIR_Z: P1.10, R9.2
DIR_Z_OUT: U12.3, Z_PLUG_SOCKET1.3
GND: C3.1, C6.1, P1.4, P2.2, R22.1, R22.2, U1.3, U2.2, U2.3, U3.3, U4.3, U5.3, U6.2, U7.2, U8.2, U9.2, U10.2, U11.2, U12.2, U13.2, U14.3, U16.3
GNDPWR: C2.2, C5.2, POWER_IN1.2, R20.2, U15.1, X_PLUG_SOCKET1.7, Y1_PLUG_SOCKET1.7, Y2_PLUG_SOCKET1.7, Z_PLUG_SOCKET1.7
GNDS: C1.2, C4.2, POWER_IN2.2, PROBE1.2, R20.1, SPINDLE1.4, U1.2, X_PLUG_SOCKET1.2, X_PLUG_SOCKET1.4, Y1_PLUG_SOCKET1.2, Y1_PLUG_SOCKET1.4, Y2_PLUG_SOCKET1.2, Y2_PLUG_SOCKET1.4, Z_PLUG_SOCKET1.2, Z_PLUG_SOCKET1.4
LIM_X: P1.12, R23.2, U4.4
LIM_X_IN: U4.2, X_PLUG_SOCKET1.8
LIM_Y: P1.13, R24.2, U5.4
LIM_Y_IN: U5.2, Y1_PLUG_SOCKET1.8, Y2_PLUG_SOCKET1.8
LIM_Z: P1.15, R25.2, U14.4
LIM_Z_IN: U14.2, Z_PLUG_SOCKET1.8
unnamed: C4.1, R27.1, SPINDLE1.3
unnamed: D1.2, R21.1
unnamed: R1.1, U6.1
unnamed: R2.1, U4.1
unnamed: R2.2, S1JA-13-F1.2
unnamed: R3.1, U5.1
unnamed: R3.2, S1JA-13-F2.2
unnamed: R4.1, U14.1
unnamed: R4.2, S1JA-13-F3.2
unnamed: R5.1, U8.1
unnamed: R6.1, U9.1
unnamed: R7.1, U10.1
unnamed: R8.1, U11.1
unnamed: R9.1, U12.1
unnamed: R10.1, U13.1
unnamed: R11.1, U7.1
unnamed: R12.1, U1.1
unnamed: R13.1, U3.1
unnamed: R14.1, U16.1
unnamed: R15.1, U1.4, U2.1
unnamed: R19.2, U9.3
PROBE: P2.7, R26.2, U16.4
PUL_X: P1.5, R1.2
PUL_X_OUT: U6.3, X_PLUG_SOCKET1.1
PUL_Y: P1.6, R5.2
PUL_Y_OUT: U8.3, Y1_PLUG_SOCKET1.1, Y2_PLUG_SOCKET1.1
PUL_Z: P1.7, R6.2
PUL_Z_OUT: R19.1, Z_PLUG_SOCKET1.1
SPINDLE_EN: P2.15, R10.2
SPINDLE_PWM: P1.14, R11.2

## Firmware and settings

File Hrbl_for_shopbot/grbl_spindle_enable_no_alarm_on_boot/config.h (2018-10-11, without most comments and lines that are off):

#define config_h
#include "grbl.h" // For Arduino IDE compatibility.
#define DEFAULTS_GENERIC
#define CPU_MAP_ATMEGA328P // Arduino Uno CPU
#define BAUD_RATE 115200
#define CMD_RESET 0x18 // ctrl-x.
#define CMD_STATUS_REPORT '?'
#define CMD_CYCLE_START '~'
#define CMD_FEED_HOLD '!'
#define CMD_SAFETY_DOOR 0x84
#define CMD_JOG_CANCEL  0x85
#define CMD_DEBUG_REPORT 0x86 // Only when DEBUG enabled, sends debug report in '{}' braces.
#define CMD_FEED_OVR_RESET 0x90         // Restores feed override value to 100%.
#define CMD_FEED_OVR_COARSE_PLUS 0x91
#define CMD_FEED_OVR_COARSE_MINUS 0x92
#define CMD_FEED_OVR_FINE_PLUS  0x93
#define CMD_FEED_OVR_FINE_MINUS  0x94
#define CMD_RAPID_OVR_RESET 0x95        // Restores rapid override value to 100%.
#define CMD_RAPID_OVR_MEDIUM 0x96
#define CMD_RAPID_OVR_LOW 0x97
#define CMD_SPINDLE_OVR_RESET 0x99      // Restores spindle override value to 100%.
#define CMD_SPINDLE_OVR_COARSE_PLUS 0x9A
#define CMD_SPINDLE_OVR_COARSE_MINUS 0x9B
#define CMD_SPINDLE_OVR_FINE_PLUS 0x9C
#define CMD_SPINDLE_OVR_FINE_MINUS 0x9D
#define CMD_SPINDLE_OVR_STOP 0x9E
#define CMD_COOLANT_FLOOD_OVR_TOGGLE 0xA0
#define CMD_COOLANT_MIST_OVR_TOGGLE 0xA1
#define HOMING_CYCLE_0 (1<<Z_AXIS)                // REQUIRED: First move Z to clear workspace.
#define HOMING_CYCLE_1 ((1<<X_AXIS)|(1<<Y_AXIS))  // OPTIONAL: Then move X,Y at the same time.
#define N_HOMING_LOCATE_CYCLE 1 // Integer (1-128)
#define N_STARTUP_LINE 2 // Integer (1-2)
#define N_DECIMAL_COORDVALUE_INCH 4 // Coordinate or position value in inches
#define N_DECIMAL_COORDVALUE_MM   3 // Coordinate or position value in mm
#define N_DECIMAL_RATEVALUE_INCH  1 // Rate or velocity value in in/min
#define N_DECIMAL_RATEVALUE_MM    0 // Rate or velocity value in mm/min
#define N_DECIMAL_SETTINGVALUE    3 // Decimals for floating point setting values
#define N_DECIMAL_RPMVALUE        0 // RPM value in rotations per min.
#define MESSAGE_PROBE_COORDINATES // Enabled by default. Comment to disable.
#define SAFETY_DOOR_SPINDLE_DELAY 4.0 // Float (seconds)
#define SAFETY_DOOR_COOLANT_DELAY 1.0 // Float (seconds)
#define CHECK_LIMITS_AT_INIT
#define DEFAULT_FEED_OVERRIDE           100 // 100%. Don't change this value.
#define MAX_FEED_RATE_OVERRIDE          200 // Percent of programmed feed rate (100-255). Usually 120% or 200%
#define MIN_FEED_RATE_OVERRIDE           10 // Percent of programmed feed rate (1-100). Usually 50% or 1%
#define FEED_OVERRIDE_COARSE_INCREMENT   10 // (1-99). Usually 10%.
#define FEED_OVERRIDE_FINE_INCREMENT      1 // (1-99). Usually 1%.
#define DEFAULT_RAPID_OVERRIDE  100 // 100%. Don't change this value.
#define RAPID_OVERRIDE_MEDIUM    50 // Percent of rapid (1-99). Usually 50%.
#define RAPID_OVERRIDE_LOW       25 // Percent of rapid (1-99). Usually 25%.
#define DEFAULT_SPINDLE_SPEED_OVERRIDE    100 // 100%. Don't change this value.
#define MAX_SPINDLE_SPEED_OVERRIDE        200 // Percent of programmed spindle speed (100-255). Usually 200%.
#define MIN_SPINDLE_SPEED_OVERRIDE         10 // Percent of programmed spindle speed (1-100). Usually 10%.
#define SPINDLE_OVERRIDE_COARSE_INCREMENT  10 // (1-99). Usually 10%.
#define SPINDLE_OVERRIDE_FINE_INCREMENT     1 // (1-99). Usually 1%.
#define RESTORE_OVERRIDES_AFTER_PROGRAM_END // Default enabled. Comment to disable.
#define REPORT_FIELD_BUFFER_STATE // Default enabled. Comment to disable.
#define REPORT_FIELD_PIN_STATE // Default enabled. Comment to disable.
#define REPORT_FIELD_CURRENT_FEED_SPEED // Default enabled. Comment to disable.
#define REPORT_FIELD_WORK_COORD_OFFSET // Default enabled. Comment to disable.
#define REPORT_FIELD_OVERRIDES // Default enabled. Comment to disable.
#define REPORT_FIELD_LINE_NUMBERS // Default enabled. Comment to disable.
#define REPORT_OVR_REFRESH_BUSY_COUNT 20  // (1-255)
#define REPORT_OVR_REFRESH_IDLE_COUNT 10  // (1-255) Must be less than or equal to the busy count
#define REPORT_WCO_REFRESH_BUSY_COUNT 30  // (2-255)
#define REPORT_WCO_REFRESH_IDLE_COUNT 10  // (2-255) Must be less than or equal to the busy count
#define ACCELERATION_TICKS_PER_SECOND 100
#define ADAPTIVE_MULTI_AXIS_STEP_SMOOTHING  // Default enabled. Comment to disable.
#define TOOL_LENGTH_OFFSET_AXIS Z_AXIS // Default z-axis. Valid values are X_AXIS, Y_AXIS, or Z_AXIS.
#define VARIABLE_SPINDLE // Default enabled. Comment to disable.
 #define USE_SPINDLE_DIR_AS_ENABLE_PIN // Default disabled. Uncomment to enable.
#define MINIMUM_JUNCTION_SPEED 0.0 // (mm/min)
#define MINIMUM_FEED_RATE 1.0 // (mm/min)
#define N_ARC_CORRECTION 12 // Integer (1-255)
#define ARC_ANGULAR_TRAVEL_EPSILON 5E-7 // Float (radians)
#define DWELL_TIME_STEP 50 // Integer (1-255) (milliseconds)
#define ENABLE_RESTORE_EEPROM_WIPE_ALL         // '$RST=*' Default enabled. Comment to disable.
#define ENABLE_RESTORE_EEPROM_DEFAULT_SETTINGS // '$RST=$' Default enabled. Comment to disable.
#define ENABLE_RESTORE_EEPROM_CLEAR_PARAMETERS // '$RST=#' Default enabled. Comment to disable.
#define ENABLE_BUILD_INFO_WRITE_COMMAND // '$I=' Default enabled. Comment to disable.
#define FORCE_BUFFER_SYNC_DURING_EEPROM_WRITE // Default enabled. Comment to disable.
#define FORCE_BUFFER_SYNC_DURING_WCO_CHANGE // Default enabled. Comment to disable.
#define PARKING_AXIS Z_AXIS // Define which axis that performs the parking motion
#define PARKING_TARGET -5.0 // Parking axis target. In mm, as machine coordinate [-max_travel,0].
#define PARKING_RATE 500.0 // Parking fast rate after pull-out in mm/min.
#define PARKING_PULLOUT_RATE 100.0 // Pull-out/plunge slow feed rate in mm/min.
#define PARKING_PULLOUT_INCREMENT 5.0 // Spindle pull-out and plunge distance in mm. Incremental distance.
#define DISABLE_LASER_DURING_HOLD // Default enabled. Comment to disable.
#define N_PIECES 4  // Integer (1-4). Number of piecewise lines used in script solution.
#define RPM_MAX  11686.4  // Max RPM of model. $30 > RPM_MAX will be limited to RPM_MAX.
#define RPM_MIN  202.5    // Min RPM of model. $31 < RPM_MIN will be limited to RPM_MIN.
#define RPM_POINT12  6145.4  // Used N_PIECES >=2. Junction point between lines 1 and 2.
#define RPM_POINT23  9627.8  // Used N_PIECES >=3. Junction point between lines 2 and 3.
#define RPM_POINT34  10813.9 // Used N_PIECES = 4. Junction point between lines 3 and 4.
#define RPM_LINE_A1  3.197101e-03  // Used N_PIECES >=1. A and B constants of line 1.
#define RPM_LINE_B1  -3.526076e-1
#define RPM_LINE_A2  1.722950e-2   // Used N_PIECES >=2. A and B constants of line 2.
#define RPM_LINE_B2  8.588176e+01
#define RPM_LINE_A3  5.901518e-02  // Used N_PIECES >=3. A and B constants of line 3.
#define RPM_LINE_B3  4.881851e+02
#define RPM_LINE_A4  1.203413e-01  // Used N_PIECES = 4. A and B constants of line 4.
#define RPM_LINE_B4  1.151360e+03

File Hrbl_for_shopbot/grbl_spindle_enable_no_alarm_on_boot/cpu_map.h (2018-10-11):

/*
  cpu_map.h - CPU and pin mapping configuration file
  Part of Grbl

  Copyright (c) 2012-2016 Sungeun K. Jeon for Gnea Research LLC

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
  You should have received a copy of the GNU General Public License
  along with Grbl.  If not, see <http://www.gnu.org/licenses/>.
*/

/* The cpu_map.h files serve as a central pin mapping selection file for different
   processor types or alternative pin layouts. This version of Grbl officially supports
   only the Arduino Mega328p. */


#ifndef cpu_map_h
#define cpu_map_h


#ifdef CPU_MAP_ATMEGA328P // (Arduino Uno) Officially supported by Grbl.

  // Define serial port pins and interrupt vectors.
  #define SERIAL_RX     USART_RX_vect
  #define SERIAL_UDRE   USART_UDRE_vect

  // Define step pulse output pins. NOTE: All step bit pins must be on the same port.
  #define STEP_DDR        DDRD
  #define STEP_PORT       PORTD
  #define X_STEP_BIT      2  // Uno Digital Pin 2
  #define Y_STEP_BIT      3  // Uno Digital Pin 3
  #define Z_STEP_BIT      4  // Uno Digital Pin 4
  #define STEP_MASK       ((1<<X_STEP_BIT)|(1<<Y_STEP_BIT)|(1<<Z_STEP_BIT)) // All step bits

  // Define step direction output pins. NOTE: All direction pins must be on the same port.
  #define DIRECTION_DDR     DDRD
  #define DIRECTION_PORT    PORTD
  #define X_DIRECTION_BIT   5  // Uno Digital Pin 5
  #define Y_DIRECTION_BIT   6  // Uno Digital Pin 6
  #define Z_DIRECTION_BIT   7  // Uno Digital Pin 7
  #define DIRECTION_MASK    ((1<<X_DIRECTION_BIT)|(1<<Y_DIRECTION_BIT)|(1<<Z_DIRECTION_BIT)) // All direction bits

  // Define stepper driver enable/disable output pin.
  #define STEPPERS_DISABLE_DDR    DDRB
  #define STEPPERS_DISABLE_PORT   PORTB
  #define STEPPERS_DISABLE_BIT    0  // Uno Digital Pin 8
  #define STEPPERS_DISABLE_MASK   (1<<STEPPERS_DISABLE_BIT)

  // Define homing/hard limit switch input pins and limit interrupt vectors.
  // NOTE: All limit bit pins must be on the same port, but not on a port with other input pins (CONTROL).
  #define LIMIT_DDR        DDRB
  #define LIMIT_PIN        PINB
  #define LIMIT_PORT       PORTB
  #define X_LIMIT_BIT      1  // Uno Digital Pin 9
  #define Y_LIMIT_BIT      2  // Uno Digital Pin 10
  #ifdef VARIABLE_SPINDLE // Z Limit pin and spindle enabled swapped to access hardware PWM on Pin 11.
    #define Z_LIMIT_BIT	   4 // Uno Digital Pin 12
  #else
    #define Z_LIMIT_BIT    3  // Uno Digital Pin 11
  #endif
  #define LIMIT_MASK       ((1<<X_LIMIT_BIT)|(1<<Y_LIMIT_BIT)|(1<<Z_LIMIT_BIT)) // All limit bits
  #define LIMIT_INT        PCIE0  // Pin change interrupt enable pin
  #define LIMIT_INT_vect   PCINT0_vect
  #define LIMIT_PCMSK      PCMSK0 // Pin change interrupt register

  // Define spindle enable and spindle direction output pins.
  #define SPINDLE_ENABLE_DDR    DDRB
  #define SPINDLE_ENABLE_PORT   PORTB
  // Z Limit pin and spindle PWM/enable pin swapped to access hardware PWM on Pin 11.
  #ifdef VARIABLE_SPINDLE
    #ifdef USE_SPINDLE_DIR_AS_ENABLE_PIN
      // If enabled, spindle direction pin now used as spindle enable, while PWM remains on D11.
      #define SPINDLE_ENABLE_BIT    5  // Uno Digital Pin 13 (NOTE: D13 can't be pulled-high input due to LED.)
    #else
      #define SPINDLE_ENABLE_BIT    3  // Uno Digital Pin 11
    #endif
  #else
    #define SPINDLE_ENABLE_BIT    4  // Uno Digital Pin 12
  #endif
  #ifndef USE_SPINDLE_DIR_AS_ENABLE_PIN
    #define SPINDLE_DIRECTION_DDR   DDRB
    #define SPINDLE_DIRECTION_PORT  PORTB
    #define SPINDLE_DIRECTION_BIT   5  // Uno Digital Pin 13 (NOTE: D13 can't be pulled-high input due to LED.)
  #endif

  // Define flood and mist coolant enable output pins.
  #define COOLANT_FLOOD_DDR   DDRC
  #define COOLANT_FLOOD_PORT  PORTC
  #define COOLANT_FLOOD_BIT   3  // Uno Analog Pin 3
  #define COOLANT_MIST_DDR   DDRC
  #define COOLANT_MIST_PORT  PORTC
  #define COOLANT_MIST_BIT   4  // Uno Analog Pin 4

  // Define user-control controls (cycle start, reset, feed hold) input pins.
  // NOTE: All CONTROLs pins must be on the same port and not on a port with other input pins (limits).
  #define CONTROL_DDR       DDRC
  #define CONTROL_PIN       PINC
  #define CONTROL_PORT      PORTC
  #define CONTROL_RESET_BIT         0  // Uno Analog Pin 0
  #define CONTROL_FEED_HOLD_BIT     1  // Uno Analog Pin 1
  #define CONTROL_CYCLE_START_BIT   2  // Uno Analog Pin 2
  #define CONTROL_SAFETY_DOOR_BIT   1  // Uno Analog Pin 1 NOTE: Safety door is shared with feed hold. Enabled by config define.
  #define CONTROL_INT       PCIE1  // Pin change interrupt enable pin
  #define CONTROL_INT_vect  PCINT1_vect
  #define CONTROL_PCMSK     PCMSK1 // Pin change interrupt register
  #define CONTROL_MASK      ((1<<CONTROL_RESET_BIT)|(1<<CONTROL_FEED_HOLD_BIT)|(1<<CONTROL_CYCLE_START_BIT)|(1<<CONTROL_SAFETY_DOOR_BIT))
  #define CONTROL_INVERT_MASK   CONTROL_MASK // May be re-defined to only invert certain control pins.

  // Define probe switch input pin.
  #define PROBE_DDR       DDRC
  #define PROBE_PIN       PINC
  #define PROBE_PORT      PORTC
  #define PROBE_BIT       5  // Uno Analog Pin 5
  #define PROBE_MASK      (1<<PROBE_BIT)

  // Variable spindle configuration below. Do not change unless you know what you are doing.
  // NOTE: Only used when variable spindle is enabled.
  #define SPINDLE_PWM_MAX_VALUE     255 // Don't change. 328p fast PWM mode fixes top value as 255.
  #ifndef SPINDLE_PWM_MIN_VALUE
    #define SPINDLE_PWM_MIN_VALUE   1   // Must be greater than zero.
  #endif
  #define SPINDLE_PWM_OFF_VALUE     0
  #define SPINDLE_PWM_RANGE         (SPINDLE_PWM_MAX_VALUE-SPINDLE_PWM_MIN_VALUE)
  #define SPINDLE_TCCRA_REGISTER	  TCCR2A
  #define SPINDLE_TCCRB_REGISTER	  TCCR2B
  #define SPINDLE_OCR_REGISTER      OCR2A
  #define SPINDLE_COMB_BIT	        COM2A1

  // Prescaled, 8-bit Fast PWM mode.
  #define SPINDLE_TCCRA_INIT_MASK   ((1<<WGM20) | (1<<WGM21))  // Configures fast PWM mode.
  // #define SPINDLE_TCCRB_INIT_MASK   (1<<CS20)               // Disable prescaler -> 62.5kHz
  // #define SPINDLE_TCCRB_INIT_MASK   (1<<CS21)               // 1/8 prescaler -> 7.8kHz (Used in v0.9)
  // #define SPINDLE_TCCRB_INIT_MASK   ((1<<CS21) | (1<<CS20)) // 1/32 prescaler -> 1.96kHz
  #define SPINDLE_TCCRB_INIT_MASK      (1<<CS22)               // 1/64 prescaler -> 0.98kHz (J-tech laser)

  // NOTE: On the 328p, these must be the same as the SPINDLE_ENABLE settings.
  #define SPINDLE_PWM_DDR	  DDRB
  #define SPINDLE_PWM_PORT  PORTB
  #define SPINDLE_PWM_BIT	  3    // Uno Digital Pin 11

#endif

/*
#ifdef CPU_MAP_CUSTOM_PROC
  // For a custom pin map or different processor, copy and edit one of the available cpu
  // map files and modify it to your needs. Make sure the defined name is also changed in
  // the config.h file.
#endif
*/

#endif

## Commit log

2018-10-11 Hrbl shield RAW, needs updates for shopbot
    [nano.kicad_pcb, nano.sch]
2018-10-11 GRBL source code with HRBL settings
    [config.h, cpu_map.h, defaults.h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]
2018-10-11 BOM and DXF
    [nano_BOM.ods]
2018-10-11 added manual for shopbot motor and driver
2018-10-12 pwm smooth circuit
    [pwm_smooth.kicad_pcb, pwm_smooth.sch]
2018-10-12 Updated schematic
    [pwm_smooth.sch]
2018-10-15 Updated with 24V Contactor signal and PWM filter
    [nano.kicad_pcb, nano.sch]
2018-10-15 CNC mill ready DXF for single axis board
    [single-axis-test-CNC-ready.dxf]
2018-10-15 kicad project files for single axis board
    [single-axis-test.kicad_pcb, single-axis-test.sch]
2018-10-22 ShopBot: add wiring diagrams (power, control)
2018-10-22 added images of milling bits used for the test
2018-10-22 added description of milling bits used in the test
2018-10-23 add drill holes toolpath
2018-10-23 add isolation milling toolpath
2018-10-24 Hattori: PCB milling test number 2
2018-10-28 shopbot document on calibrating steps per mm
2018-10-28 udated single axis test board
    [single-axis-test-CNC-ready.dxf, single-axis-test.sch]
2018-10-28 udated motor pinout
2018-10-28 tweaked single axis board
    [single-axis-test.sch]
2018-11-05 Kicad files
    [nano.sch]
2018-11-22 add grbl config for Hattori
2018-11-23 add probe Z gcode for Hattori (from Jens D. dropbox)
2019-01-30 macros for the small milling machine

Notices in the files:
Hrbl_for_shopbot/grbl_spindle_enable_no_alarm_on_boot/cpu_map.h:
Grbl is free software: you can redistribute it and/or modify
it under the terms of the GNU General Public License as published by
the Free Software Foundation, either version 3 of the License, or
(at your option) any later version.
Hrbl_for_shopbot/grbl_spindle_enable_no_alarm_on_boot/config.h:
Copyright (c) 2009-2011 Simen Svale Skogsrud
